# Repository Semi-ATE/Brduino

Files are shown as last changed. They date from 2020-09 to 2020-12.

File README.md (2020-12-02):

# Brduino-Nano

Brduino-Nano is a 'jeux de mots vis-à-vis' [Arduino-Nano](https://store.arduino.cc/arduino-nano).

It is an open-source project sponsored by [RevisionOne](https://www.revisionone.de/) that brings the Arduino-Nano form-factor into this century. :sunglasses:

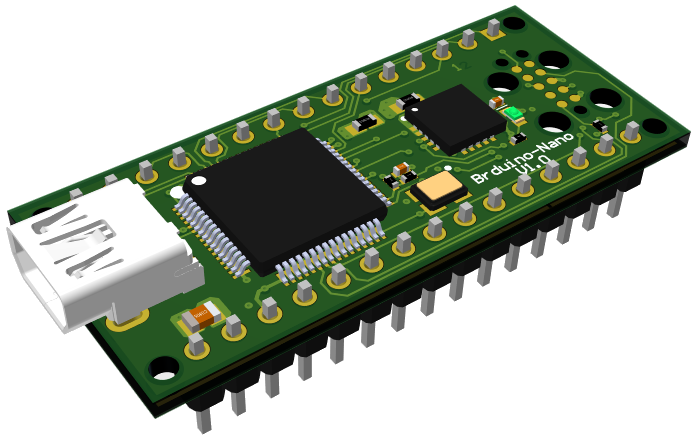
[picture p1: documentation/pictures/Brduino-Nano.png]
Brduino-Nano


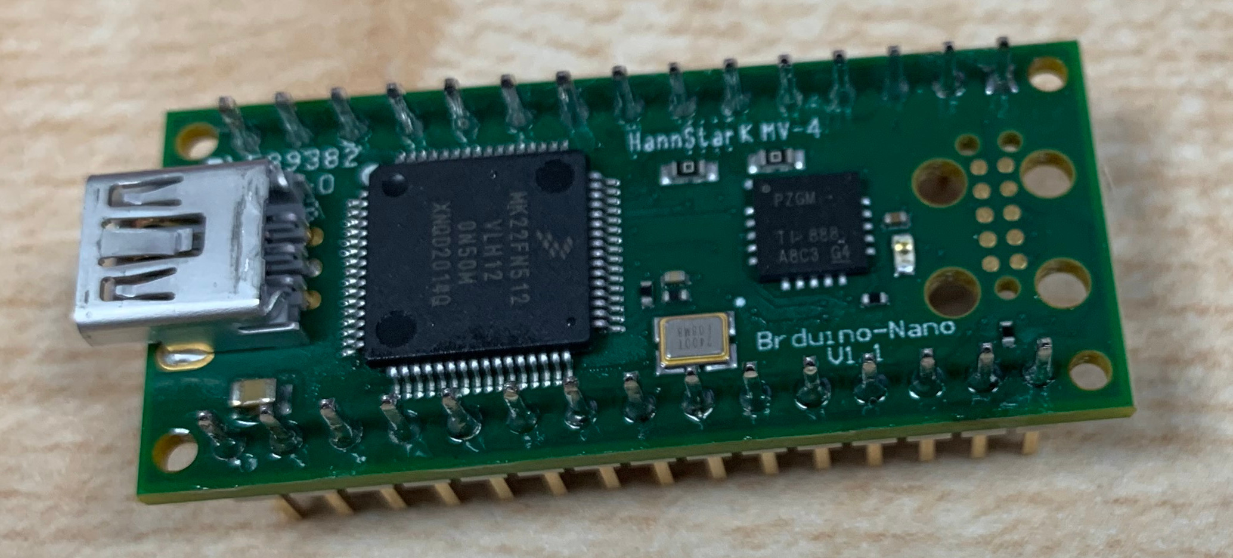
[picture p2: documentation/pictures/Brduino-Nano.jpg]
Brduino-Nano


Whereas the Arduino Nano is based on the [8-Bit ATmega328](https://www.microchip.com/wwwproducts/en/ATmega328) controller from [Microchip](https://www.microchip.com/), the Brduino Nano is based on the [32-Bit Arm Cortex M4](https://developer.arm.com/ip-products/processors/cortex-m/cortex-m4) from [NXP](https://www.nxp.com/part/MK22FN512VLH12#/). 
Below a quick comparison of the Arduino-Nano against the Brduino-Nano :

|  | Arduino-Nano | Brduino-Nano | 
|---|:---|:---|
| Microcontroller | [ATmega328](https://www.microchip.com/wwwproducts/en/ATmega328) | [MK22FN512VLH12](https://www.nxp.com/part/MK22FN512VLH12#/) |
| Architecture | 8-Bit AVR | 32-Bit Cortex M4 |
| Operating Voltage |  5 V | 3.3 V |
| Flash Memory | 32 KB | 512 KB |
| SRAM | 2 KB | 128 KB |
| Clock Speed | 16 MHz | 120 MHz |
| DAC | N/A | 1 x 12 Bit |
| Timers | 2 x 8 Bit / 1 x 16 Bit | 1 x 16 Bit|
| ADC | 1 x 10 Bit | 2 x 16 Bit |
| Analog IN Pins | 8 | 8 |
| DC Current per I/O Pins |	40 mA (I/O Pins) | ? |
| Input Voltage | 7-12 V | 5 V |
| Digital I/O Pins | 22 (6 of which are PWM) | 22 (? of which are PWM) |
| PWM Output | 	6 | ? |
| Power Consumption | 19 mA | ? |
| PCB Size | 18 x 45 mm | 18 x 45 mm |
| Weight |	7 g | 7 g |

The Brduino ofcourse doesn't use the ugly [arduino IDE](https://www.arduino.cc/en/main/software) but the [eclipse](https://www.eclipse.org/) based [MCUXpresso](https://www.nxp.com/design/software/development-software/mcuxpresso-software-and-tools-/mcuxpresso-integrated-development-environment-ide:MCUXpresso-IDE) :stuck_out_tongue_winking_eye:.

Connecting from your IDE to the Brduino is done via a [JLink Pro](https://www.segger.com/products/debug-probes/j-link/models/j-link-pro/) in combination with the [10-Pin Needle Adapter](https://www.segger.com/products/debug-probes/j-link/accessories/adapters/10-pin-needle-adapter/).

The project is realized in [Altium Designer](https://www.altium.com/altium-designer/), but, as the gerbers are included in the repo, you can produce the Brduino yourself without having Altium license(s), or alternatively you can contact [Thomas Arul](thomasarul@likom.com.my) at [Likom](http://www.likom.com.my/) to get a quote for these things. 

When creating a project based on the Brduino-Nano, you can create a a new repository base on the [Brduino-Nano-Template](https://github.com/Semi-ATE/Brduino-Nano-Template) repository, this way you get all the 'goodies' out of the box.

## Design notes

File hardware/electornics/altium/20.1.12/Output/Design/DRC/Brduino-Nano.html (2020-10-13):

Altium

# Design Rule Verification Report

Date: | | 10/13/2020
Time: | | 1:15:41 PM
Elapsed Time: | | 00:00:01
Filename: | | C:\Users\hoeren\Desktop\Repos\Semi-ATE\Brduino-Nano\hardware\electornics\altium\20.1.12\Brduino-Nano.PcbDoc

Warnings: | | 0
Rule Violations: | | 0

## Summary

Warnings | Count
Total | 0

Rule Violations | Count
Clearance Constraint (Gap=0.7mm) (InNetClass('HV-P')),(All) | 0
Clearance Constraint (Gap=0.152mm) (All),(All) | 0
Short-Circuit Constraint (Allowed=No) (All),(All) | 0
Un-Routed Net Constraint ( (All) ) | 0
Width Constraint (Min=0.089mm) (Max=0.254mm) (Preferred=0.254mm) (IsArc and InComponent('FID*')) | 0
Width Constraint (Min=0.152mm) (Max=5.08mm) (Preferred=0.152mm) (All) | 0
Width Constraint (Min=0.152mm) (Max=0.152mm) (Preferred=0.152mm) (InDifferentialPairClass('HighSpeedDiff')) | 0
Routing Layers(All) | 0
Routing Via (MinHoleWidth=0.203mm) (MaxHoleWidth=0.508mm) (PreferredHoleWidth=0.203mm) (MinWidth=0.508mm) (MaxWidth=1.016mm) (PreferedWidth=0.508mm) (All) | 0
Differential Pairs Uncoupled Length using the Gap Constraints (Min=0.152mm) (Max=0.254mm) (Prefered=0.152mm) and Width Constraints (Min=0.195mm) (Max=0.381mm) (Prefered=0.195mm) (InDifferentialPair('CPUSIGA.USB-D_1')) | 0
Differential Pairs Uncoupled Length using the Gap Constraints (Min=0.156mm) (Max=0.256mm) (Prefered=0.156mm) and Width Constraints (Min=0.152mm) (Max=0.381mm) (Prefered=0.152mm) (InDifferentialPairClass('HighSpeedDiff')) | 0
Power Plane Connect Rule(Direct Connect )(Expansion=0.508mm) (Conductor Width=0.254mm) (Air Gap=0.254mm) (Entries=4) (All) | 0
Hole Size Constraint (Min=0.2mm) (Max=5.08mm) (All) | 0
Pads and Vias to follow the Drill pairs settings | 0
Hole To Hole Clearance (Gap=0.254mm) (All),(All) | 0
Minimum Solder Mask Sliver (Gap=0.08mm) (Disabled)(All),(All) | 0
Net Antennae (Tolerance=0mm) (Disabled)(All) | 0
Matched Lengths(Tolerance=0.254mm) (InxSignalClass('RMII-IF')) | 0
Matched Lengths(Tolerance=1mm) (InDifferentialPair('ETH-TX_8') or InDifferentialPair('ETH-RX_8') or InDifferentialPair('CPUSIGA.USB-D_1')) | 0
Room U_Brduino-MCU1 (Bounding Region = (29.769mm, 76.759mm, 70.256mm, 90.424mm) (InComponentClass('U_Brduino-MCU1')) | 0
Room Brduino-Main (Bounding Region = (25.721mm, 73.721mm, 69.967mm, 93.583mm) (InComponentClass('Brduino-Main')) | 0
Room U_Brduino-MCU-Main (Bounding Region = (23.749mm, 76.81mm, 53.34mm, 89.383mm) (Disabled)(InComponentClass('U_Brduino-MCU-Main')) | 0
Room U_Brduino-PwrLin (Bounding Region = (52.095mm, 79.451mm, 64.287mm, 88.748mm) (Disabled)(InComponentClass('U_Brduino-PwrLin')) | 0
Height Constraint (Min=0mm) (Max=25.4mm) (Prefered=12.7mm) (Disabled)(All) | 0
Total | 0

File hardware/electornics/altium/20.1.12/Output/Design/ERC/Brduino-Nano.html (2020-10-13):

Altium

# Electrical Rule Check Report

Date: | | 10/13/2020
Time: | | 1:15:40 PM
Filename: | | C:\Users\hoeren\Desktop\Repos\Semi-ATE\Brduino-Nano\hardware\electornics\altium\20.1.12\.\Output\Design\ERC\Brduino-Nano.html

Class | Document | Message
Warning | Brduino-Main.SchDoc | Net 5V has no driving source (Pin C20-2, Pin C21-2, Pin J1-27, Pin J1-30, Pin J5-1, Pin R25-1, Pin U2-12, Pin U2-14, Pin U2-15, Pin U2-16, Pin U2-17)
Warning | Brduino-PwrLin.SchDoc | Net NetC19_2 has no driving source (Pin C19-2, Pin U2-3)
Warning | Brduino-PwrLin.SchDoc | Net NetC22_1 has no driving source (Pin C22-1, Pin U2-13)
Warning | Brduino-MCU1.SchDoc | Net NetU1_20 has no driving source (Pin U1-20, Pin Y1-1)
Warning | Brduino-MCU1.SchDoc | Net VBAT_M_3 has no driving source (Pin R4-1, Pin U1-21)
Warning | Brduino-MCU1.SchDoc | Net Vregin_3 has no driving source (Pin C5-1, Pin R1-2, Pin R10-2, Pin U1-8)
Warning | Brduino-Main.SchDoc | Nets Wire 3V3 has multiple names (Net Label PowerOut, Port PowerOut, Power Object 3V3, Power Object 3V3, Power Object 3V3, Power Object 3V3, Power Object 3V3, Power Object 3V3, Power Object 3V3, Power Object 3V3, Power Object 3V3, Power Object 3V3, Power Object 3V3, Power Object 3V3, Sheet Entry U_Brduino-PwrLin-PowerOut(Passive))
Warning | Brduino-Main.SchDoc | Nets Wire 5V has multiple names (Net Label Bias, Net Label PowerIn, Net Label PowerIn, Port Bias, Port PowerIn, Power Object 5V, Power Object 5V, Power Object 5V, Power Object 5V, Sheet Entry U_Brduino-PwrLin-Bias(Input), Sheet Entry U_Brduino-PwrLin-PowerIn(Input))
Warning | Brduino-MCU-Main.SchDoc | Nets Wire EXTAL0_2 has multiple names (Net Label EXTAL0, Net Label EXTAL0, Net Label PTA18, Net Label PTA18, Port PTA18, Sheet Entry U_Brduino-MCU1-PTA18(I/O))
Warning | Brduino-Main.SchDoc | Nets Wire PGOOD1_1 has multiple names (Net Label PGOOD, Net Label PGOOD, Net Label PGOOD1, Port PGOOD, Sheet Entry U_Brduino-PwrLin-PGOOD(Output))
Warning | Brduino-MCU-Main.SchDoc | Nets Wire PTA19_2 has multiple names (Net Label PTA19, Net Label PTA19, Net Label XTAL0, Net Label XTAL0, Port PTA19, Sheet Entry U_Brduino-MCU1-PTA19(I/O))
Warning | Brduino-MCU-Main.SchDoc | Nets Wire PTC6_2 has multiple names (Net Label PTC6, Net Label PTC6, Net Label USB-V-Bus, Net Label USB-V-Bus, Port PTC6, Sheet Entry U_Brduino-MCU1-PTC6(I/O))
Warning | Brduino-MCU-Main.SchDoc | Nets Wire USB-D_2_N has multiple names (Net Label USB-D_N, Net Label USB-D_N, Net Label USB_N, Net Label USB_N, Port USB_N, Sheet Entry U_Brduino-MCU1-USB_N(I/O))
Warning | Brduino-MCU-Main.SchDoc | Nets Wire USB-D_2_P has multiple names (Net Label USB-D_P, Net Label USB-D_P, Net Label USB_P, Net Label USB_P, Port USB_P, Sheet Entry U_Brduino-MCU1-USB_P(I/O))
Warning | Brduino-Main.SchDoc | Nets Wire VREF_1 has multiple names (Net Label VREF, Net Label VREF, Net Label VREF_OUT, Net Label VREF_OUT, Net Label VREF_OUT, Port VREF_OUT, Port VREF_OUT, Sheet Entry U_Brduino-MCU1-VREF_OUT(I/O), Sheet Entry U_Brduino-MCU-Main-VREF_OUT(I/O))

Back to top

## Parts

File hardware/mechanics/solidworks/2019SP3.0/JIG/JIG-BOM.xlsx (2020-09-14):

Part | Description | Manufacturer | MPN | Supplier | SPN | Qty | Supplier Price | Total Price
Cover_top | Cover top plate |  |  | Likom |  | 1 |  | 0
Cover_short | Cover left/right plates |  |  | Likom |  | 2 |  | 0
Cover_long | Cover front/rear plates |  |  | Likom |  | 2 |  | 0
Needlebed | Needlebed plate |  |  | Likom |  | 1 |  | 0
ISO 7046 M3x10 | Countersunk flat head cross recess screw |  |  | Likom |  | 6 |  | 0
ISO 4762 M4x16 | Socket head cap screw |  |  | Likon |  | 22 |  | 0
ISO 4762 M3x16 | Socket head cap screw |  |  | Likom |  | 2 |  | 0
JBH6-10 | bushing for locating pin | MiSUMi | JBH6-10 | MiSUMi | JBH6-10 | 2 | 7.4 | 14.8
SFTF6-55-J5-M3 | Locating pin | MiSUMi | SFTF6-55-J5-M3 | MiSUMi | SFTF6-55-J5-M3 | 2 | 13.2 | 26.4
 |  |  |  |  |  |  |  | 41.2

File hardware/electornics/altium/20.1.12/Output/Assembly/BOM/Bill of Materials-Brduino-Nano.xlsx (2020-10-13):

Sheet: BOM Report
Bill of Material for : | Brduino-Nano
Repository : | https://github.com/Semi-ATE/Brduino-Nano |  | Organization : | RevisionOne
Project Nr. : | U33115 |  | Engineer : | Mörz
Revision : | V1.1 |  | Draftsman : | Mörz
Variant : | None |  | Reviewer : | Hören
 |  |  |  | Manufacturer |  |  | Supplier
Description | Designator(s) | Value | Foot Print | Name | Part Number | Qty | Name | Part Number | UP [€] | TP [€]
CAP CER 0.1UF 25V X7R 0402 | C1, C2, C4, C5, C6, C9, C10, C11, C12, C13 | 100nF | C0402 | Yageo | CC0402KRX7R8BB104 | 10 | DigiKey | 311-2077-6-ND | 0.08 | 0.80 €
CAP CER 2.2UF 10V X5R 0603 | C3 | 2u2F | C0603 | Samsung Electro-Mechanics | CL10A225KP8NNNC | 1 | DigiKey | 1276-1085-6-ND | 0.08 | 0.08 €
CAP CER 10UF 10V X7R 0805 | C7, C8 | 10uF | C0805 | Murata Electronics | GRM21BR71A106KA73L | 2 | DigiKey | 490-10516-6-ND | 0.21 | 0.42 €
CAP CER 4.7UF 10V X7R 0805 | C14 | 4u7F | C0805 | Samsung Electro-Mechanics | CL21B475KPFNNNE | 1 | DigiKey | 1276-2972-6-ND | 0.21 | 0.21 €
CAP CER 22PF 16V C0G/NP0 0402 | C16, C17 | 22pF | C0402 | KEMET | C0402C220J4GACTU | 2 | DigiKey | 399-8954-6-ND | 0.08 | 0.16 €
CAP CER 22UF 10V X5R 0805 | C18 | 22uF | C0805 | Murata Electronics | GRM21BR61A226ME44# | 1 | DigiKey | 490-10746-6-ND | 0.49 | 0.49 €
CAP CER 10000PF 50V X7R 0402 | C19, C22 | 10nF | C0402 | Murata Electronics | GRM155R71H103KA88D | 2 | DigiKey | 490-4516-6-ND | 0.08 | 0.16 €
CAP CER 10UF 25V X5R 0805 | C20, C21 | 10uF | C0805 | Murata Electronics | GRM21BR61E106KA73L | 2 | DigiKey | 490-5523-6-ND | 0.37 | 0.74 €
DIODE ARRAY SCHOTTKY 30V SOT23-3 | D1 |  | SOT23 | ONSEMI | BAT54C | 1 | DigiKey | BAT54CFSCT-ND | 0.18 | 0.18 €
LED GREEN CLEAR 1608 SMD | D6 | Green | LED0603 | KINGBRIGHT | APHD1608LCGCK | 1 | DigiKey | 754-2031-6-ND | 0.34 | 0.34 €
CONN RCPT USB2.0 MINI AB 5P R/A | J3 |  | Molex-0565790519 | Molex | 0565790519 | 1 | DigiKey | WM17121-ND | 2.04 | 2.04 €
RES SMD 0 OHM JUMPER 1/10W 0603 | J4, J5 | 0R | JumperSMD | Yageo | RC0603JR-070RL | 2 | DigiKey | 311-0.0GRDKR-ND | 0.08 | 0.16 €
FERRITE BEAD 600 OHM 0805 1LN | L1 | 600R@100MHz | L0805 | WUERTH | 742792040 | 1 | DigiKey | 732-1620-6-ND | 0.18 | 0.18 €
MOSFET N-CHANNEL 30V 1A SC70 | Q1 |  | SOT323 | NEXPERIA | PMF250XNEX | 1 | DigiKey | 1727-2693-6-ND | 0.31 | 0.31 €
RES SMD 0 OHM JUMPER 1/16W 0402 | R1, R5, R10 | 0R | R0402 | Yageo | RC0402JR-070RL | 3 | DigiKey | 311-0.0JRDKR-ND | 0.08 | 0.24 €
RES SMD 4.7K OHM 1% 1/16W 0402 | R2, R15, R20 | 4K7 | R0402 | Yageo | RC0402FR-074K7L | 3 | DigiKey | 311-4.7KLRDKR-ND | 0.08 | 0.24 €
RES SMD 22 OHM 1% 1/16W 0402 | R3 | 22R | R0402 | Yageo | RC0402FR-0722RL | 1 | DigiKey | 311-22.0LRDKR-ND | 0.08 | 0.08 €
RES SMD 100 OHM 1% 1/16W 0402 | R4 | 100R | R0402 | Yageo | RC0402FR-07100RL | 1 | DigiKey | 311-100LRDKR-ND | 0.08 | 0.08 €
RES SMD 10K OHM 1% 1/16W 0402 | R6, R8, R16 | 10K | R0402 | Yageo | RC0402FR-0710KL | 3 | DigiKey | 311-10.0KLRDKR-ND | 0.08 | 0.24 €
RES SMD 33 OHM 1% 1/16W 0402 | R7 | 33R | R0402 | Yageo | RC0402FR-0733RL | 1 | DigiKey | 311-33.0LRDKR-ND | 0.08 | 0.08 €
RES SMD 1M OHM 1% 1/16W 0402 | R9 | 1M | R0402 | Yageo | RC0402FR-071ML | 1 | DigiKey | 311-1.00MLRDKR-ND | 0.08 | 0.08 €
RES SMD 3.9K OHM 1% 1/16W 0402 | R25 | 3K9 | R0402 | Yageo | RC0402FR-073K9L | 1 | DigiKey | 311-3.90KLRDKR-ND | 0.08 | 0.08 €
IC MCU 32BIT 512KB FLASH 64LQFP | U1 |  | NXP-SOT1699-1 | NXP USA Inc. | MK22FN512VLH12 | 1 | DigiKey | MK22FN512VLH12-ND | 7.16 | 7.16 €
IC REG LINEAR POS ADJ 2A 20VQFN | U2 |  | S-PVQFN-N20 | Texas Instruments | TPS7A8300RGWT | 1 | DigiKey | 296-36510-6-ND | 4.57 | 4.57 €
CONN HEADER VERT 15POS 2.54MM | X1, X2 |  |  | Samtec Inc. | HTSW-115-08-F-S | 2 | DigiKey | HTSW-115-08-F-S-ND | 1.03 | 2.06 €
Crystals 32.768 kHz 9.0 pF +/-20 PPM | Y1 | 32.768KHz | CM7V-T1A | Micro Crystal | CM7V-T1A-32.768k-9pF-20PPM-TA-QA T3 | 1 | Mouser | 428-201568-MG03 | 0.37 | 0.37 €
CRYSTAL 24.0000MHZ 18PF SMD | Y2 | 24.0000MHz | FA-238 | EPSON | FA-238 24.0000MB-C3 | 1 | DigiKey | SER3689DKR-ND | 0.3 | 0.30 €
 |  |  |  |  |  | 48 |  |  |  | 21.85 €

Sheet: Project Information
Project Full Path | C:\Users\hoeren\Desktop\Repos\Semi-ATE\Brduino-Nano\hardware\electornics\altium\20.1.12\Brduino-Nano.PrjPcb
Project Filename | Brduino-Nano.PrjPcb
Variant Name | None
Data-Source Filename | Brduino-Nano.PrjPcb
Data-Source Full Path | C:\Users\hoeren\Desktop\Repos\Semi-ATE\Brduino-Nano\hardware\electornics\altium\20.1.12\Brduino-Nano.PrjPcb
Title | Bill of Materials for Project [Brduino-Nano.PrjPcb] (No PCB Document Selected)
Total Quantity | 48
Report Time | 1:16 PM
Report Date | 10/13/2020
Report Date & Tine | 10/13/2020 1:16 PM
Output Name | Bill of Materials
Output Type | BOM_PartType
Output Generator Name | BOM
Output Generator Description | Bill of Materials

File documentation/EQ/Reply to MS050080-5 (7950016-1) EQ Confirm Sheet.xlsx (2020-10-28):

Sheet: EQ
瀚宇博德股份有限公司
Hannstar Board Corporation
工程問題確認單
Engineering Questions Confirm
客戶料號(Customer P/N)： |  | MS050080-5 | 日期(Date)： |  | 2020-10-12
廠內料號(HSB P/N)： |  | 7950016-1 | 製作者(Prepared by)： |  | Vincent Liu
項次 Item | 問題內容與建議 Description and Recommendation |  | 附件 Attachment | 客戶回覆 Customer Response |  | 客戶簽名 Signature & Date
Q1 | Please confirm the panelization. |  | #1 | Likom OK |  | TDK OK
Q2 | Please confirm our recommended stackup. |  | #2 |  |  | TDK OK
Q3 | We suggest adding Dummy PAD at break-away in outer layer for plating better, please confirm. |  | #3 | Likom - OK |  | TDK OK
Q4 | Board thickness control in 1.45mm+/-10% not 1.6mm, please confirm. |  |  |  |  | TDK OK
Q5 | We will add UL MARK, DC in silkscreen layer in top side, please confirm. |  |  | Likom - OK |  | TDK OK
Q6 | Soldermask color is green, Silkscreen color is white, please confirm. |  |  |  |  | TDK OK
Q7 | Surface finish is ENIG and gold thickness is 2μ", please confirm. |  |  |  |  | TDK OK
Q8 | We will not ask again for above Eqs for future revision. Please approve. |  |  |  |  | TDK OK
Q9
Q10
1.請勿修改問題與建議欄位。
Please don't modify Description and Recommendation column.
2.請於客戶回覆欄位填入回覆意見，如有附件請新增頁面。
Please enter your comment into Customer Response column, and add new sheet if any attachment.
3.回覆後請於客戶簽名欄位填入確認者及日期。
Please sign your name and date after replied.
保存期限:壹年以上 |  |  |  |  |  | S103-3-001-01A

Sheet: #1
Panel Size:3.8"*4.07" PCS Size:1.72"*0.76" (Ignore "A" & "B", they aren't match actual size)
Break-away width:8mm and no CNC Routing
1.V-CUT number total is 7.
2.We will add "MS050080-5" and "Brduino-Nano" in break-away.
3.Adding tooling and fiducial mark as below:
 | Top Side: | Round fiducial mark with Dummy dots in square shape
 | Bottom Side: | Square fiducial mark with Dummy dots in round shape

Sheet: #2
Total thickness: 58.77mil
Outer layer is 0.5oz+plating, finish copper is more than 1oz.

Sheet: #3
TOP
BOT

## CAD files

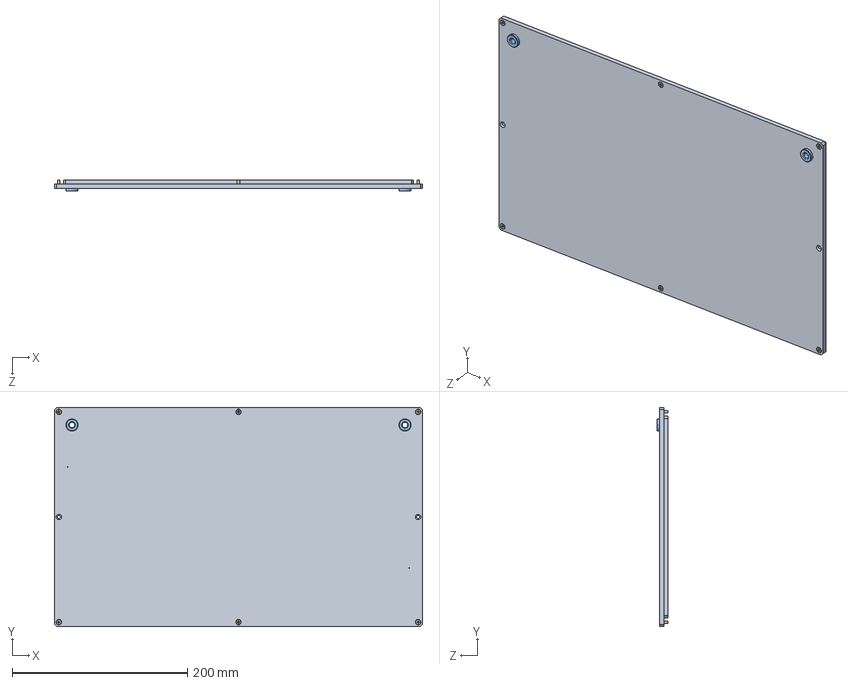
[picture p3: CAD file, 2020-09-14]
hardware/mechanics/solidworks/2019SP3.0/JIG/Needlebed.SLDASM
420.0 x 250.0 x 13.0 mm
Needlebed
countersunk flat head cross recess screw_iso x 6
JBH6_10 x 2

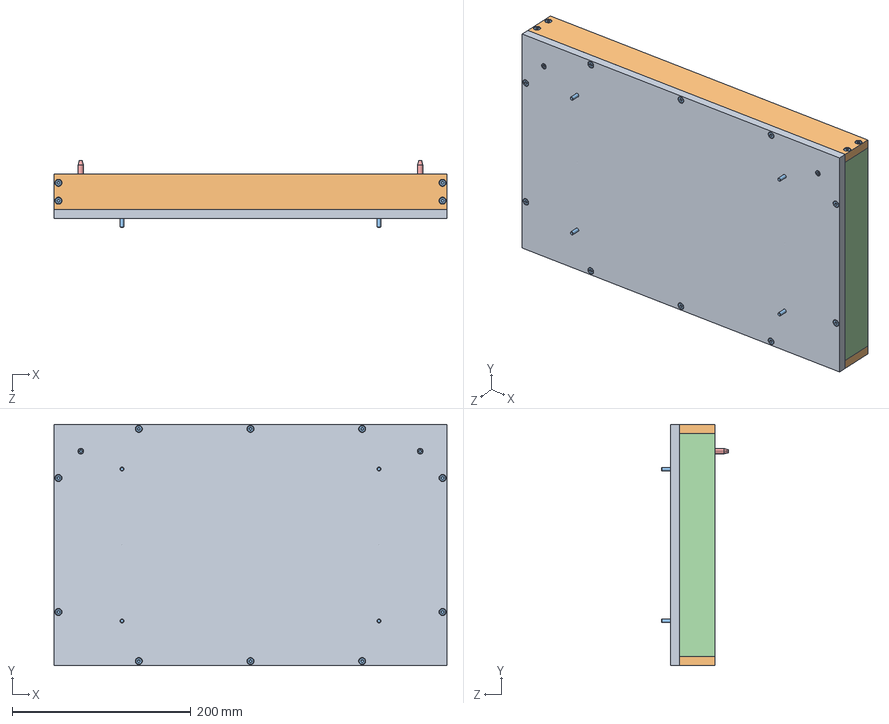
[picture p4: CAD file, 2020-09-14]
hardware/mechanics/solidworks/2019SP3.0/JIG/Cover.SLDASM
440.0 x 270.0 x 75.0 mm
Cover_top
Cover_long x 2
socket head cap screw_iso x 24
Cover_short x 2
SFTF6_55_J5_M3 x 2

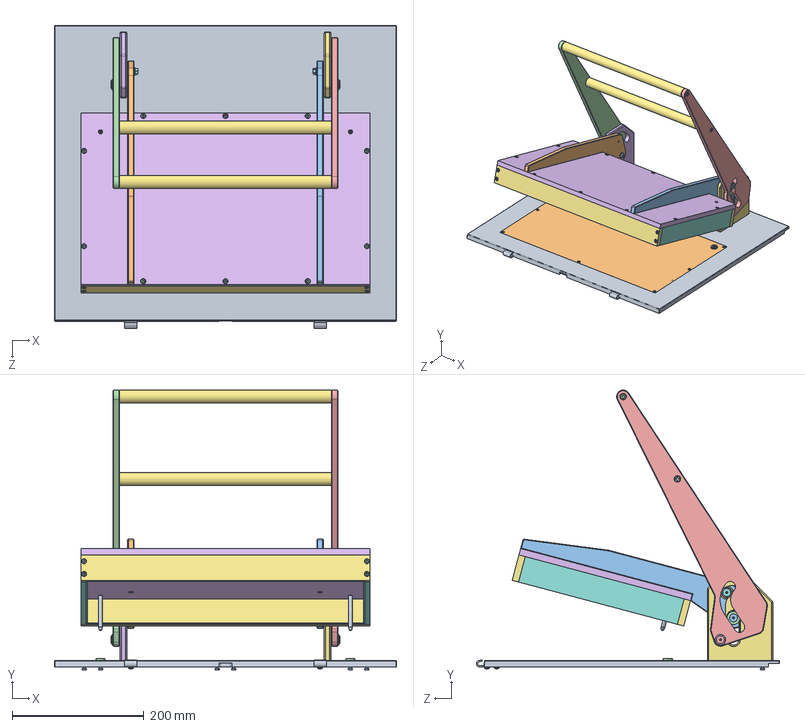
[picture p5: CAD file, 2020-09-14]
hardware/mechanics/solidworks/2019SP3.0/JIG/Fitting.SLDASM
520.0 x 425.7 x 461.0 mm
Housing_top
Lever_bottom_left
Lever_bottom_right
Lever_top_left
Lever_top_right
Spindlehouse_left
Spindlehouse_right
DBGB5-20-10 x 2
B688ZZ x 10
SWSJJ20-8-1 x 6
DBGB5-15-10 x 2
FWHJ-D16.0-H20.0-V8.0-T1.5-L4.0 x 2
DBGB5-17-5 x 2
FWHJ-D10.5-H16.0-V8.0-T1.5-L10.0 x 2
Handle x 2
FRNUT5 x 2
420111_hook x 2
pan head cross recess screw_iso x 4
slotted cheese head screw_iso x 6
socket head cap screw_iso x 32
parallel pin hardened_iso x 4
Cover_top
Cover_long x 2
Cover_short x 2
SFTF6_55_J5_M3 x 2
Needlebed
countersunk flat head cross recess screw_iso x 6
JBH6_10 x 2

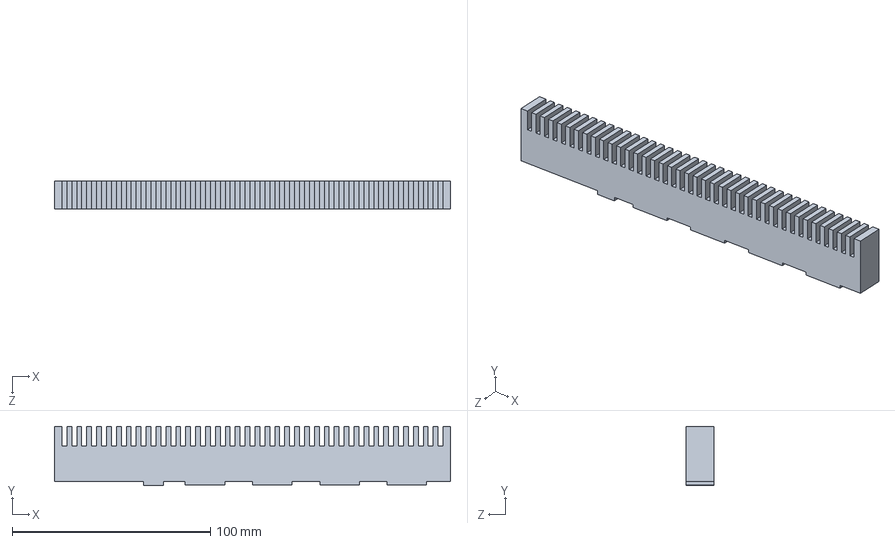
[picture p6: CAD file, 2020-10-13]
hardware/mechanics/solidworks/2019SP3.0/JIG/HeatSink.SLDPRT
200.0 x 30.0 x 14.0 mm

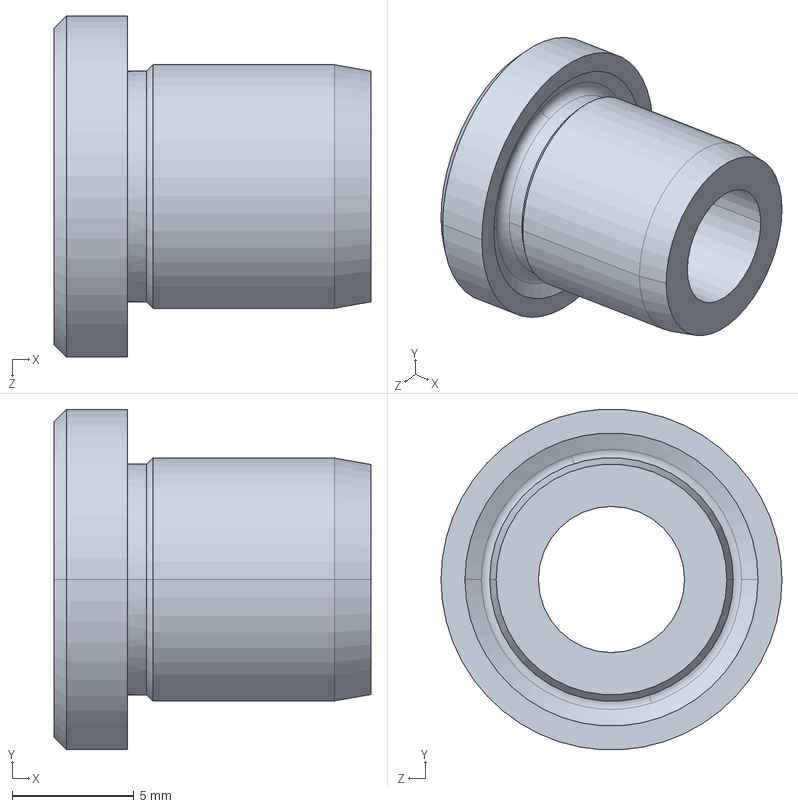
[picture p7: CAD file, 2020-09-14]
hardware/mechanics/solidworks/2019SP3.0/JIG/JBH6_10.sldprt
13.0 x 14.0 x 14.0 mm

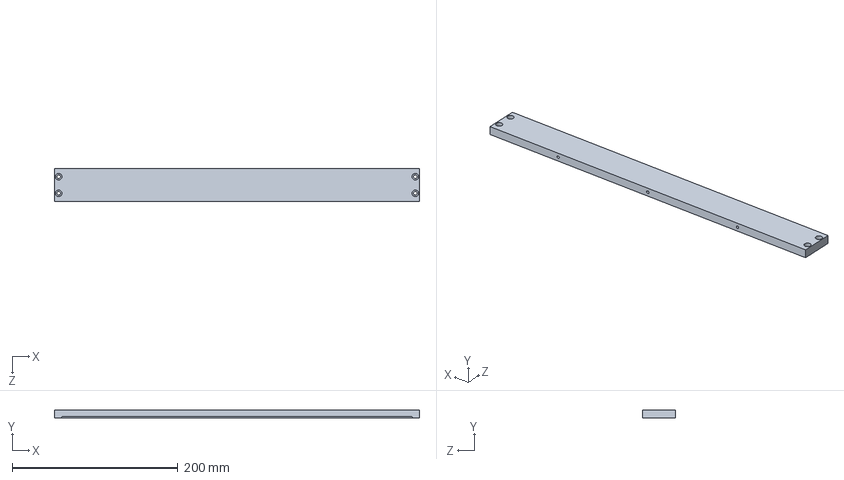
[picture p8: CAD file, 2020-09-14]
hardware/mechanics/solidworks/2019SP3.0/JIG/Cover_long.SLDPRT
440.0 x 10.0 x 40.0 mm

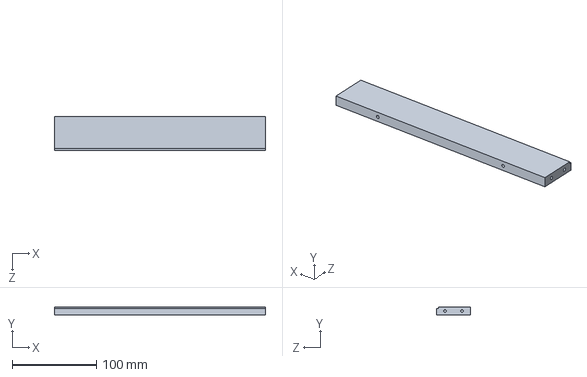
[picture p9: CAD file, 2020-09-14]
hardware/mechanics/solidworks/2019SP3.0/JIG/Cover_short.SLDPRT
250.0 x 10.0 x 40.0 mm

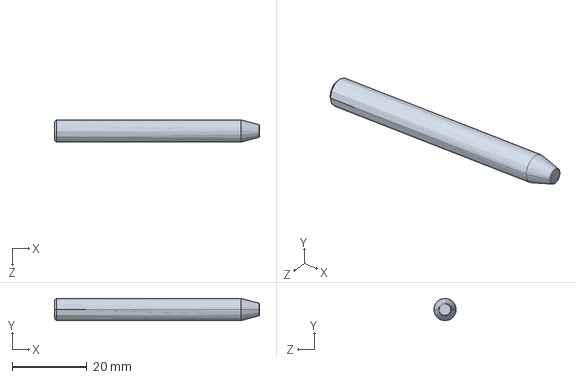
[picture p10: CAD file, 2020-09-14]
hardware/mechanics/solidworks/2019SP3.0/JIG/SFTF6_55_J5_M3.sldprt
55.0 x 6.00 x 6.00 mm

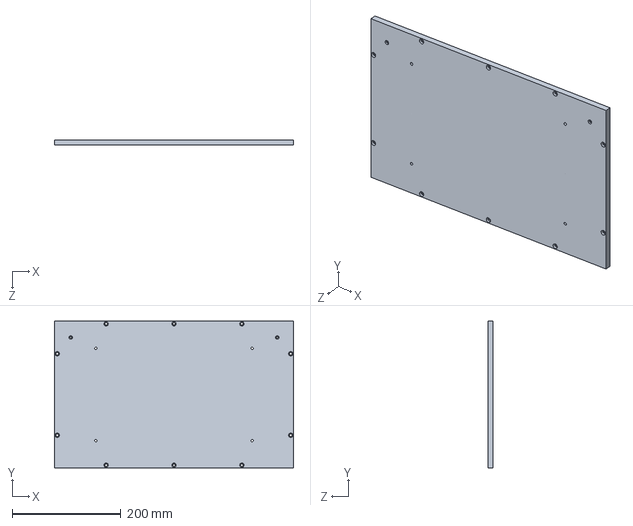
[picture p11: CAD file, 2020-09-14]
hardware/mechanics/solidworks/2019SP3.0/JIG/Cover_top.SLDPRT
440.0 x 270.0 x 10.0 mm

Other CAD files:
hardware/mechanics/solidworks/2019SP3.0/JIG/JIG.SLDDRW
hardware/mechanics/solidworks/2019SP3.0/JIG/Needlebed.SLDPRT

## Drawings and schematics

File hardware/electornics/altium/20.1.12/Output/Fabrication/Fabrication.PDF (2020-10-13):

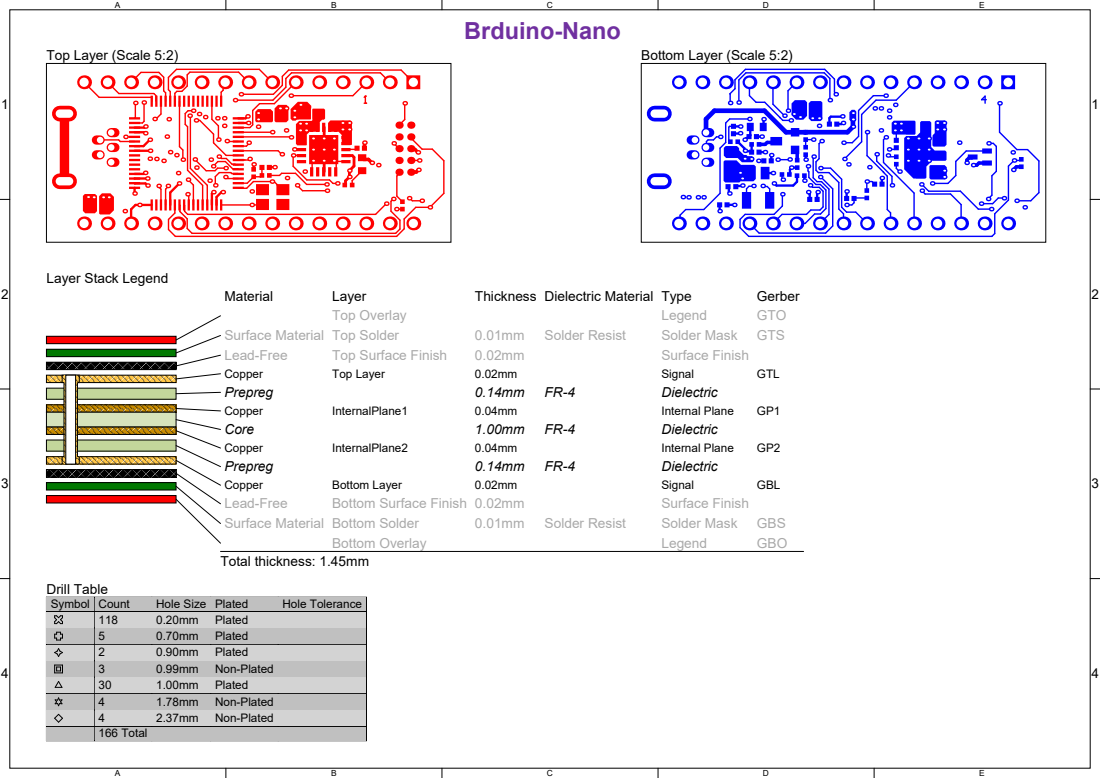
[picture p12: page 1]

Symbol | Count | Hole Size | Plated | Hole Tolerance

118 | 0.20mm | Plated
5 | 0.70mm | Plated
2 | 0.90mm | Plated
3 | 0.99mm | Non-Plated
30 | 1.00mm | Plated
4 | 1.78mm | Non-Plated
4 | 2.37mm | Non-Plated
166 Total

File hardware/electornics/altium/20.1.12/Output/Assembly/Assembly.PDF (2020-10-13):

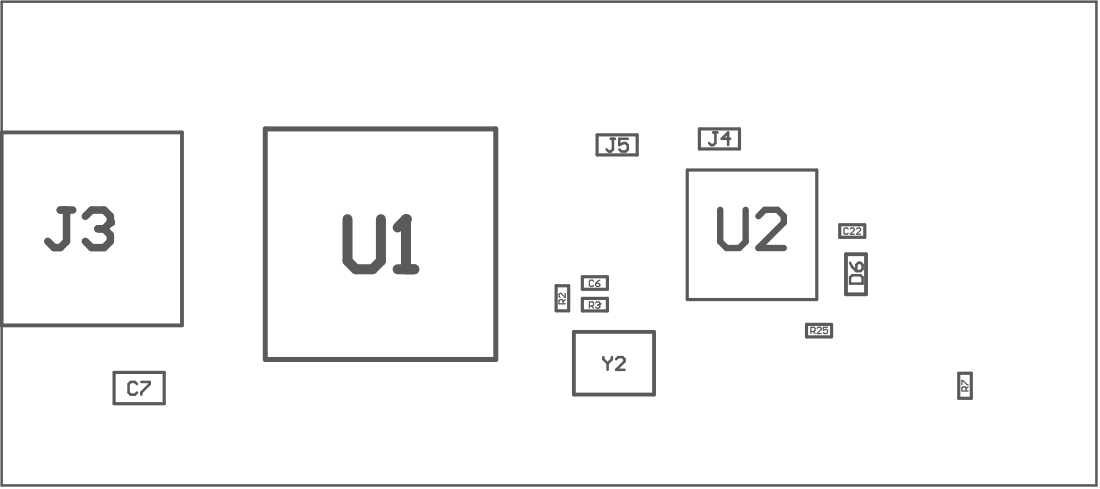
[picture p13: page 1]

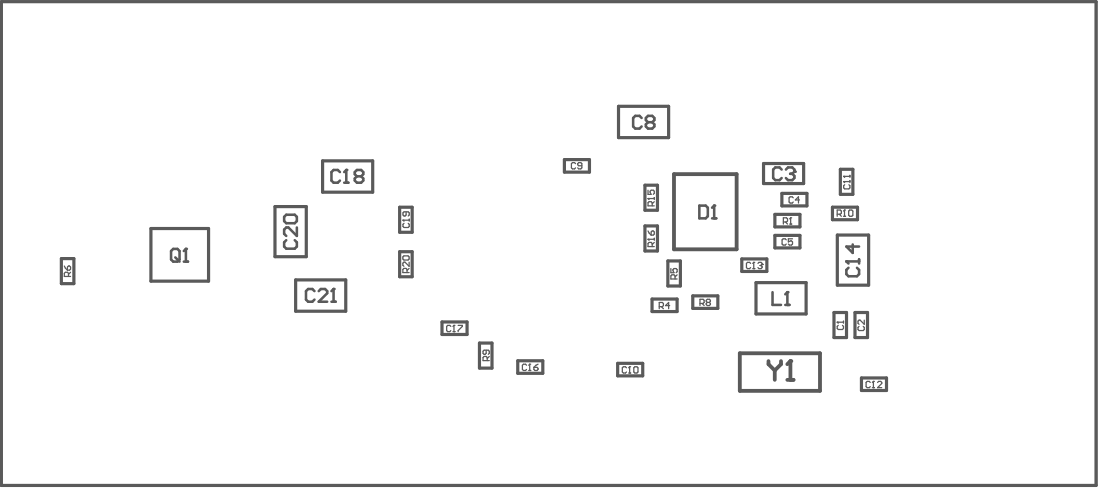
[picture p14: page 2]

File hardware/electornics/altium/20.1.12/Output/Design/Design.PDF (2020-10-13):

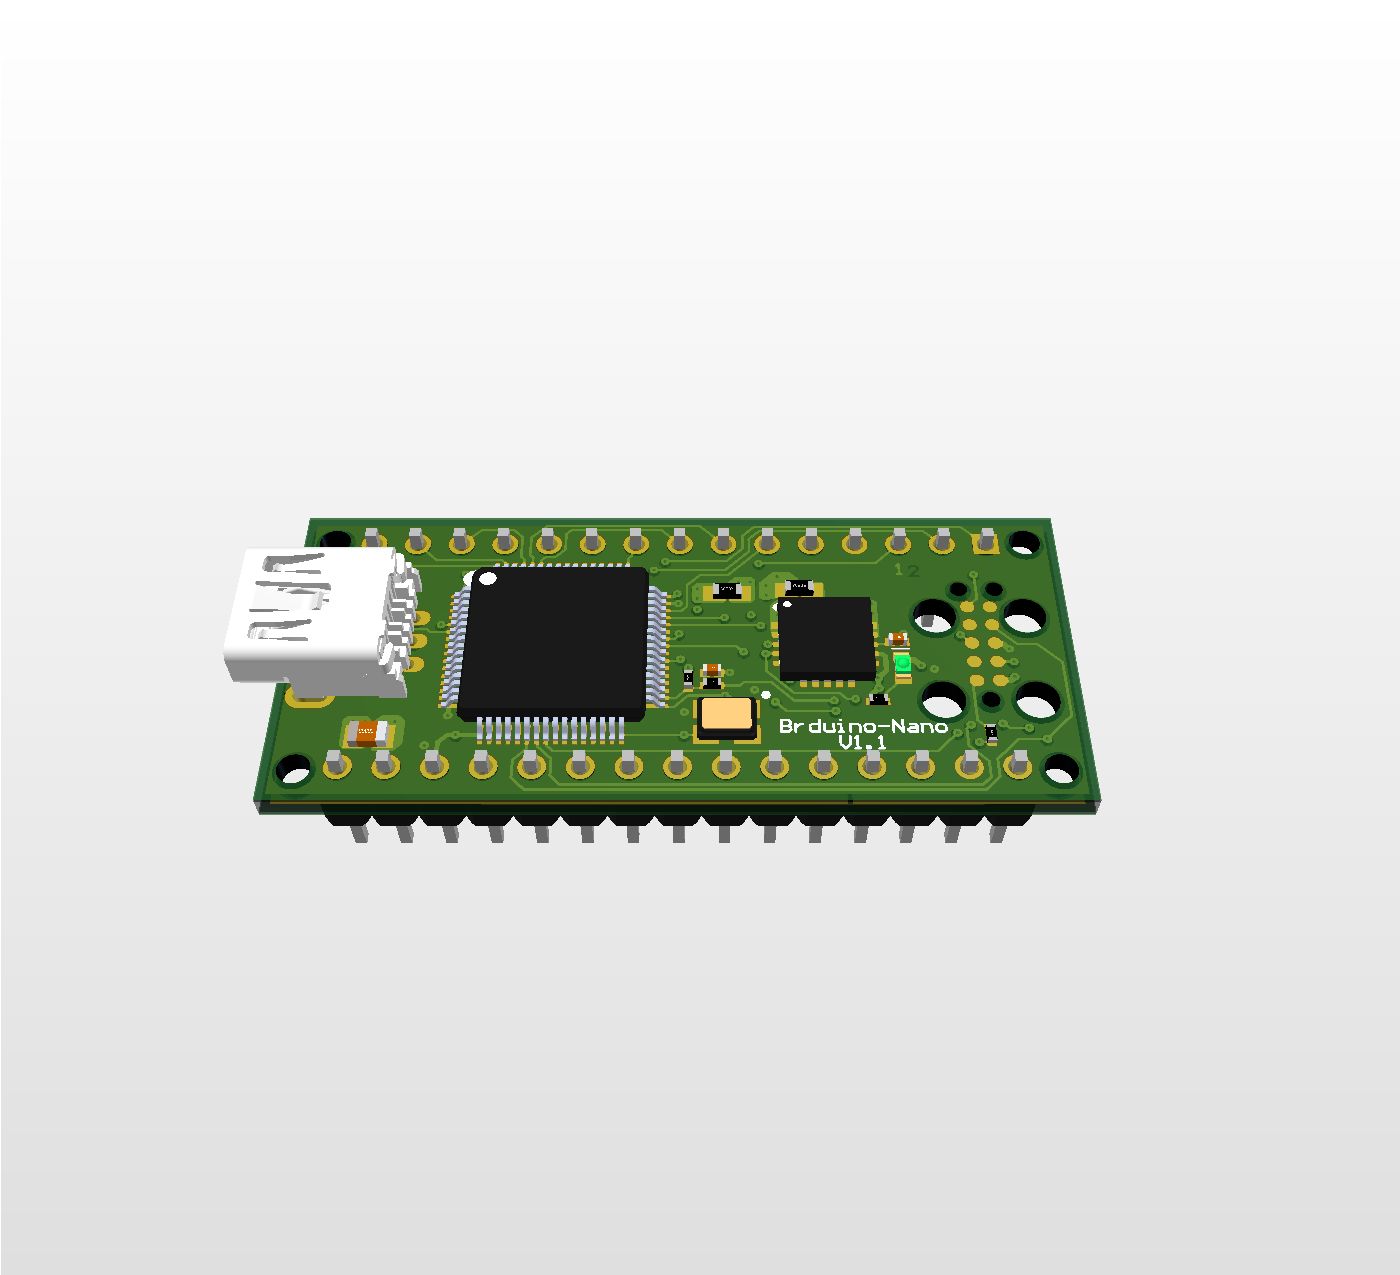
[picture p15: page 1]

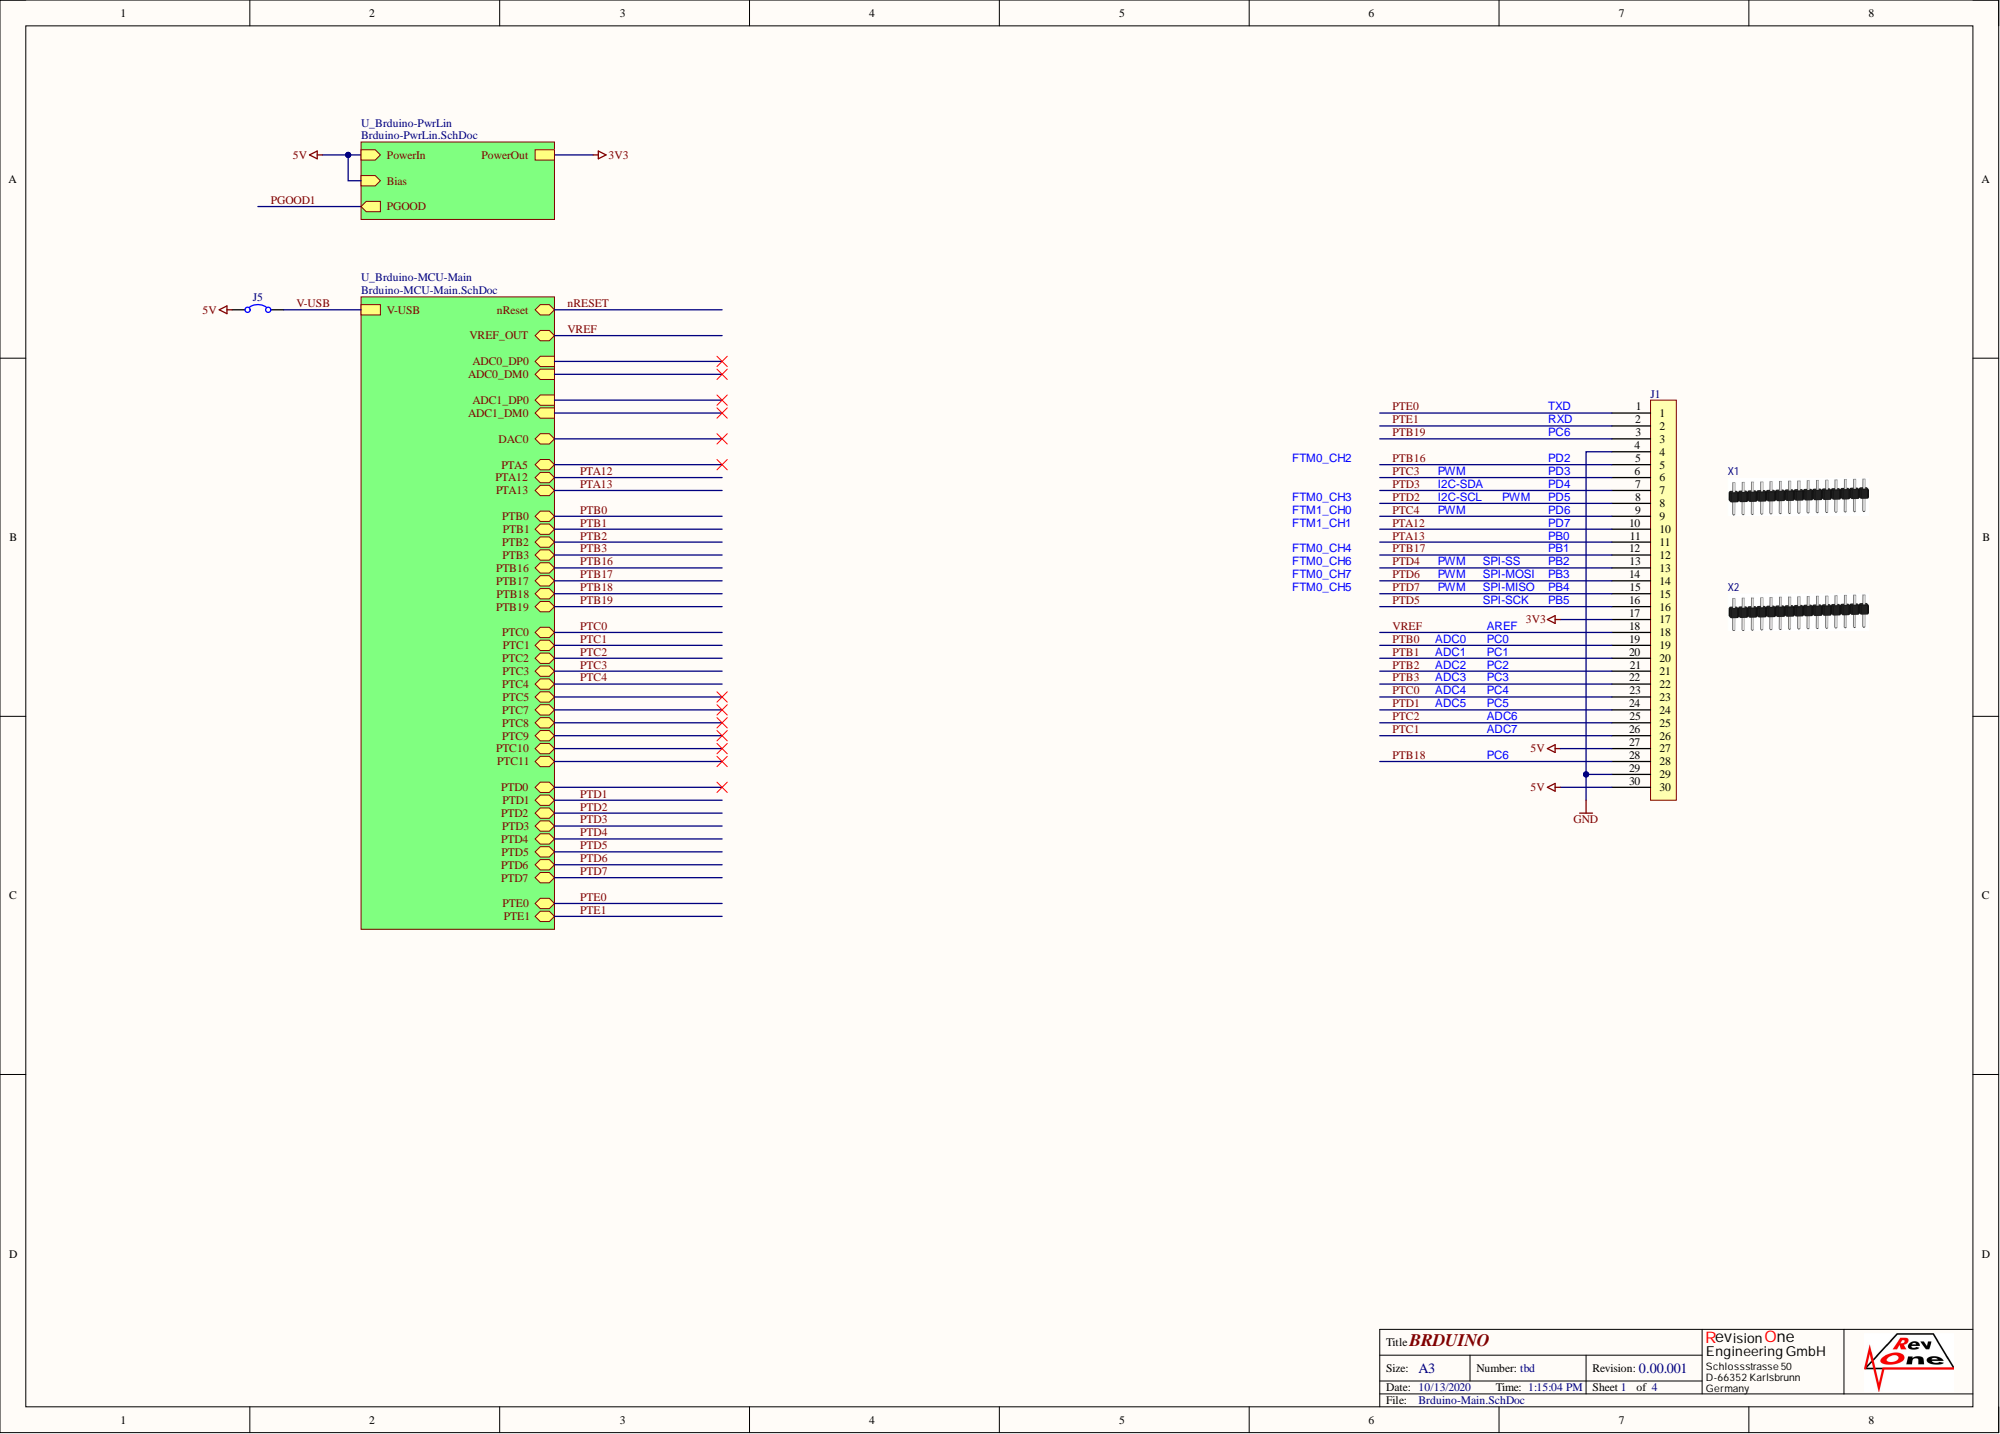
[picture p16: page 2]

U_Brduino-MCU-Main
Brduino-MCU-Main.SchDoc
V-USB

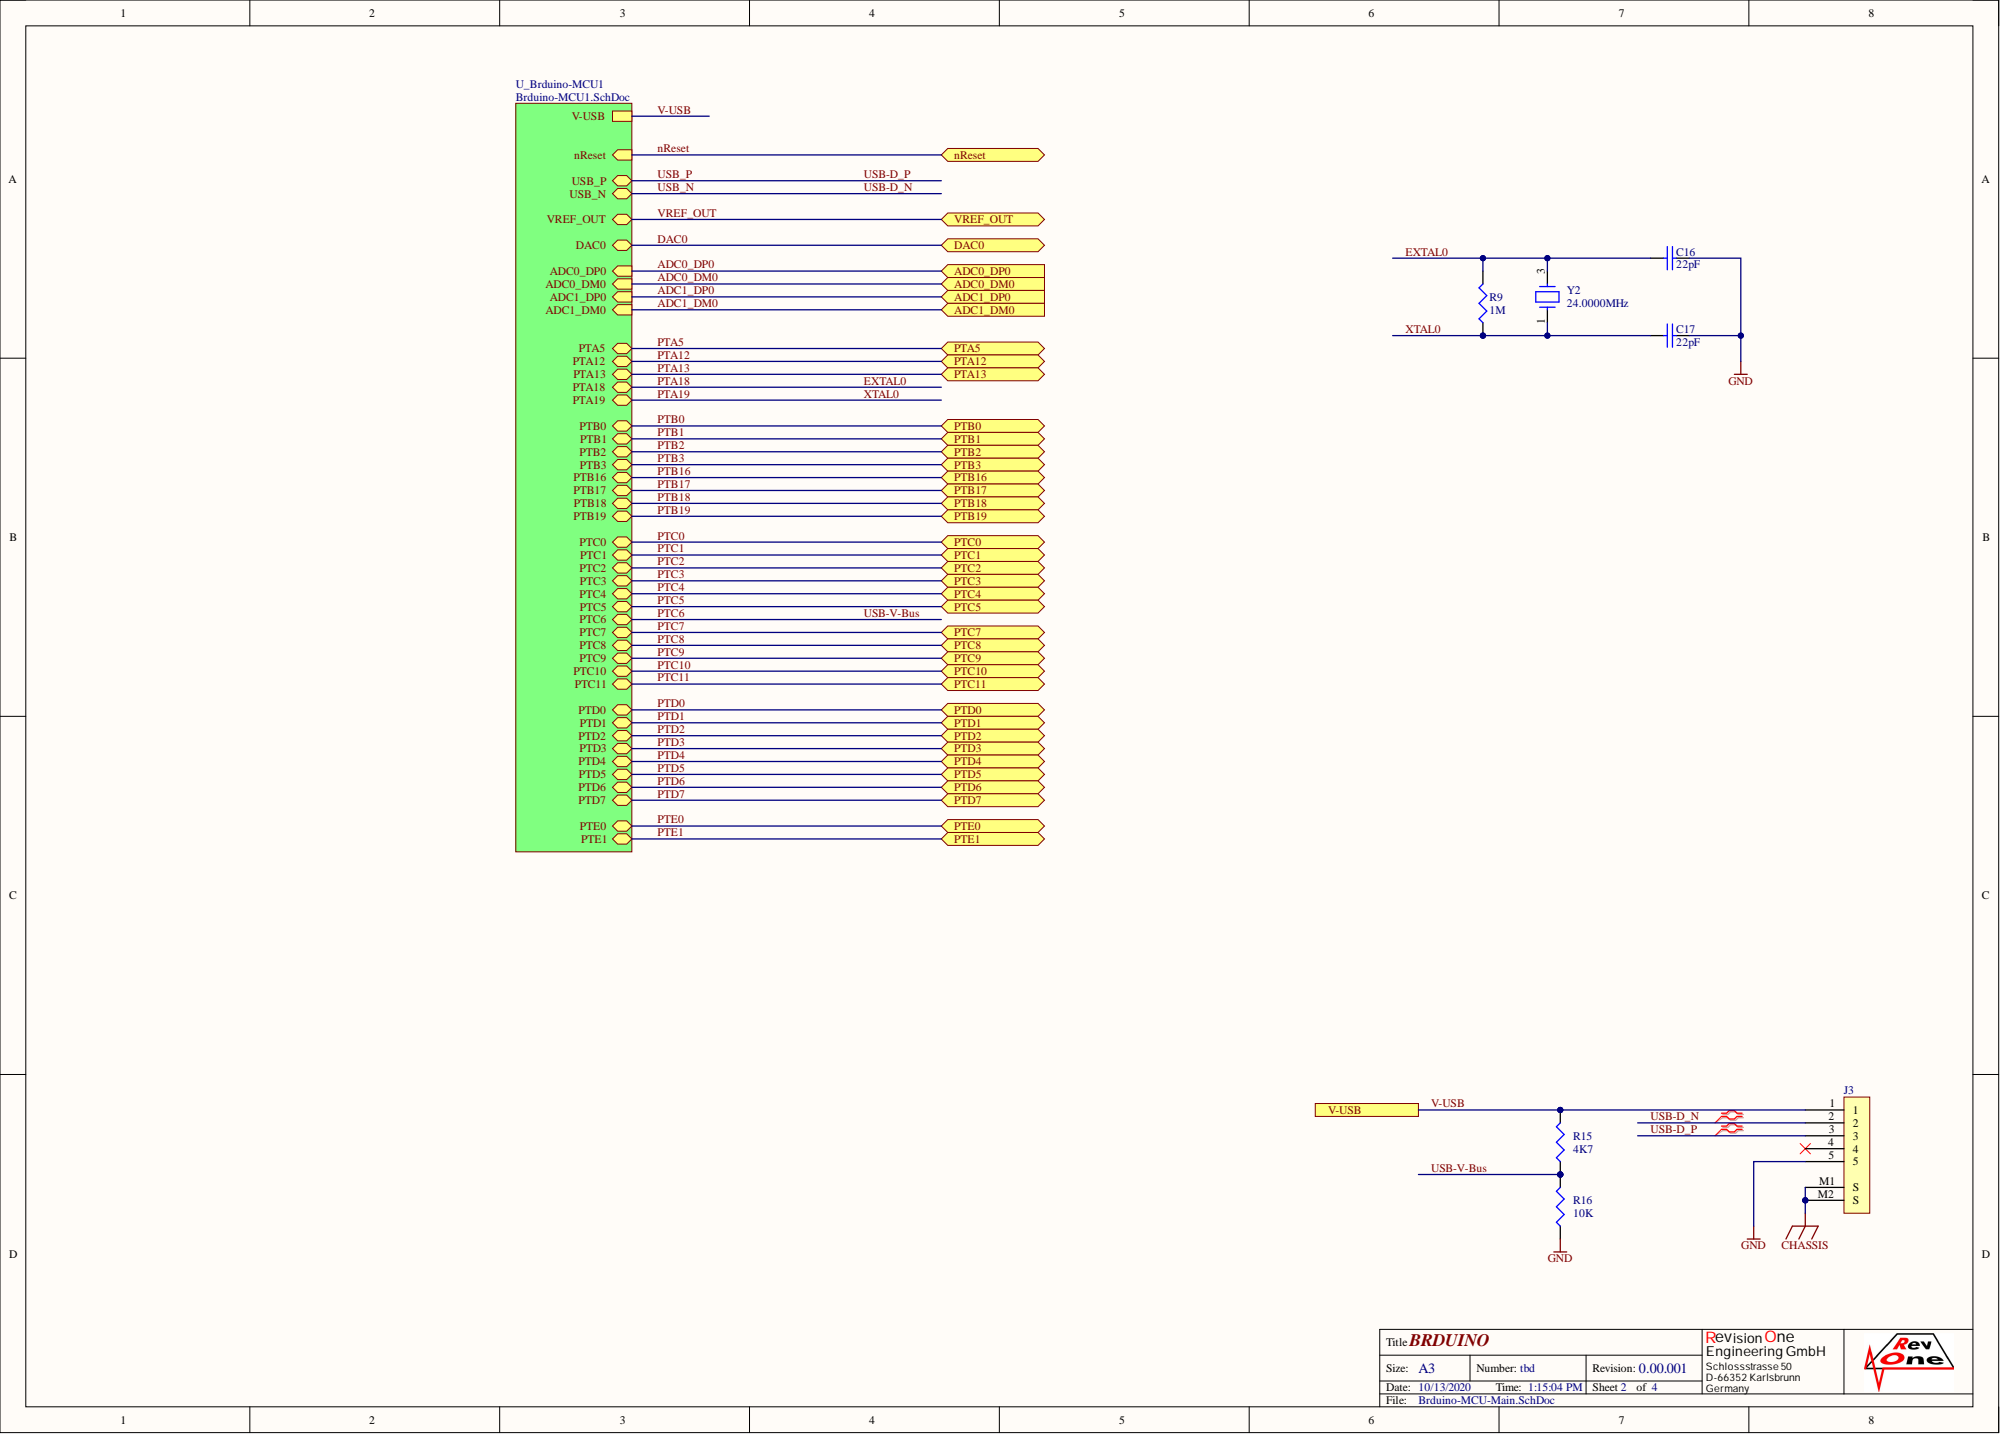
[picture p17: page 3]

Brduino-MCU-Main.SchDoc

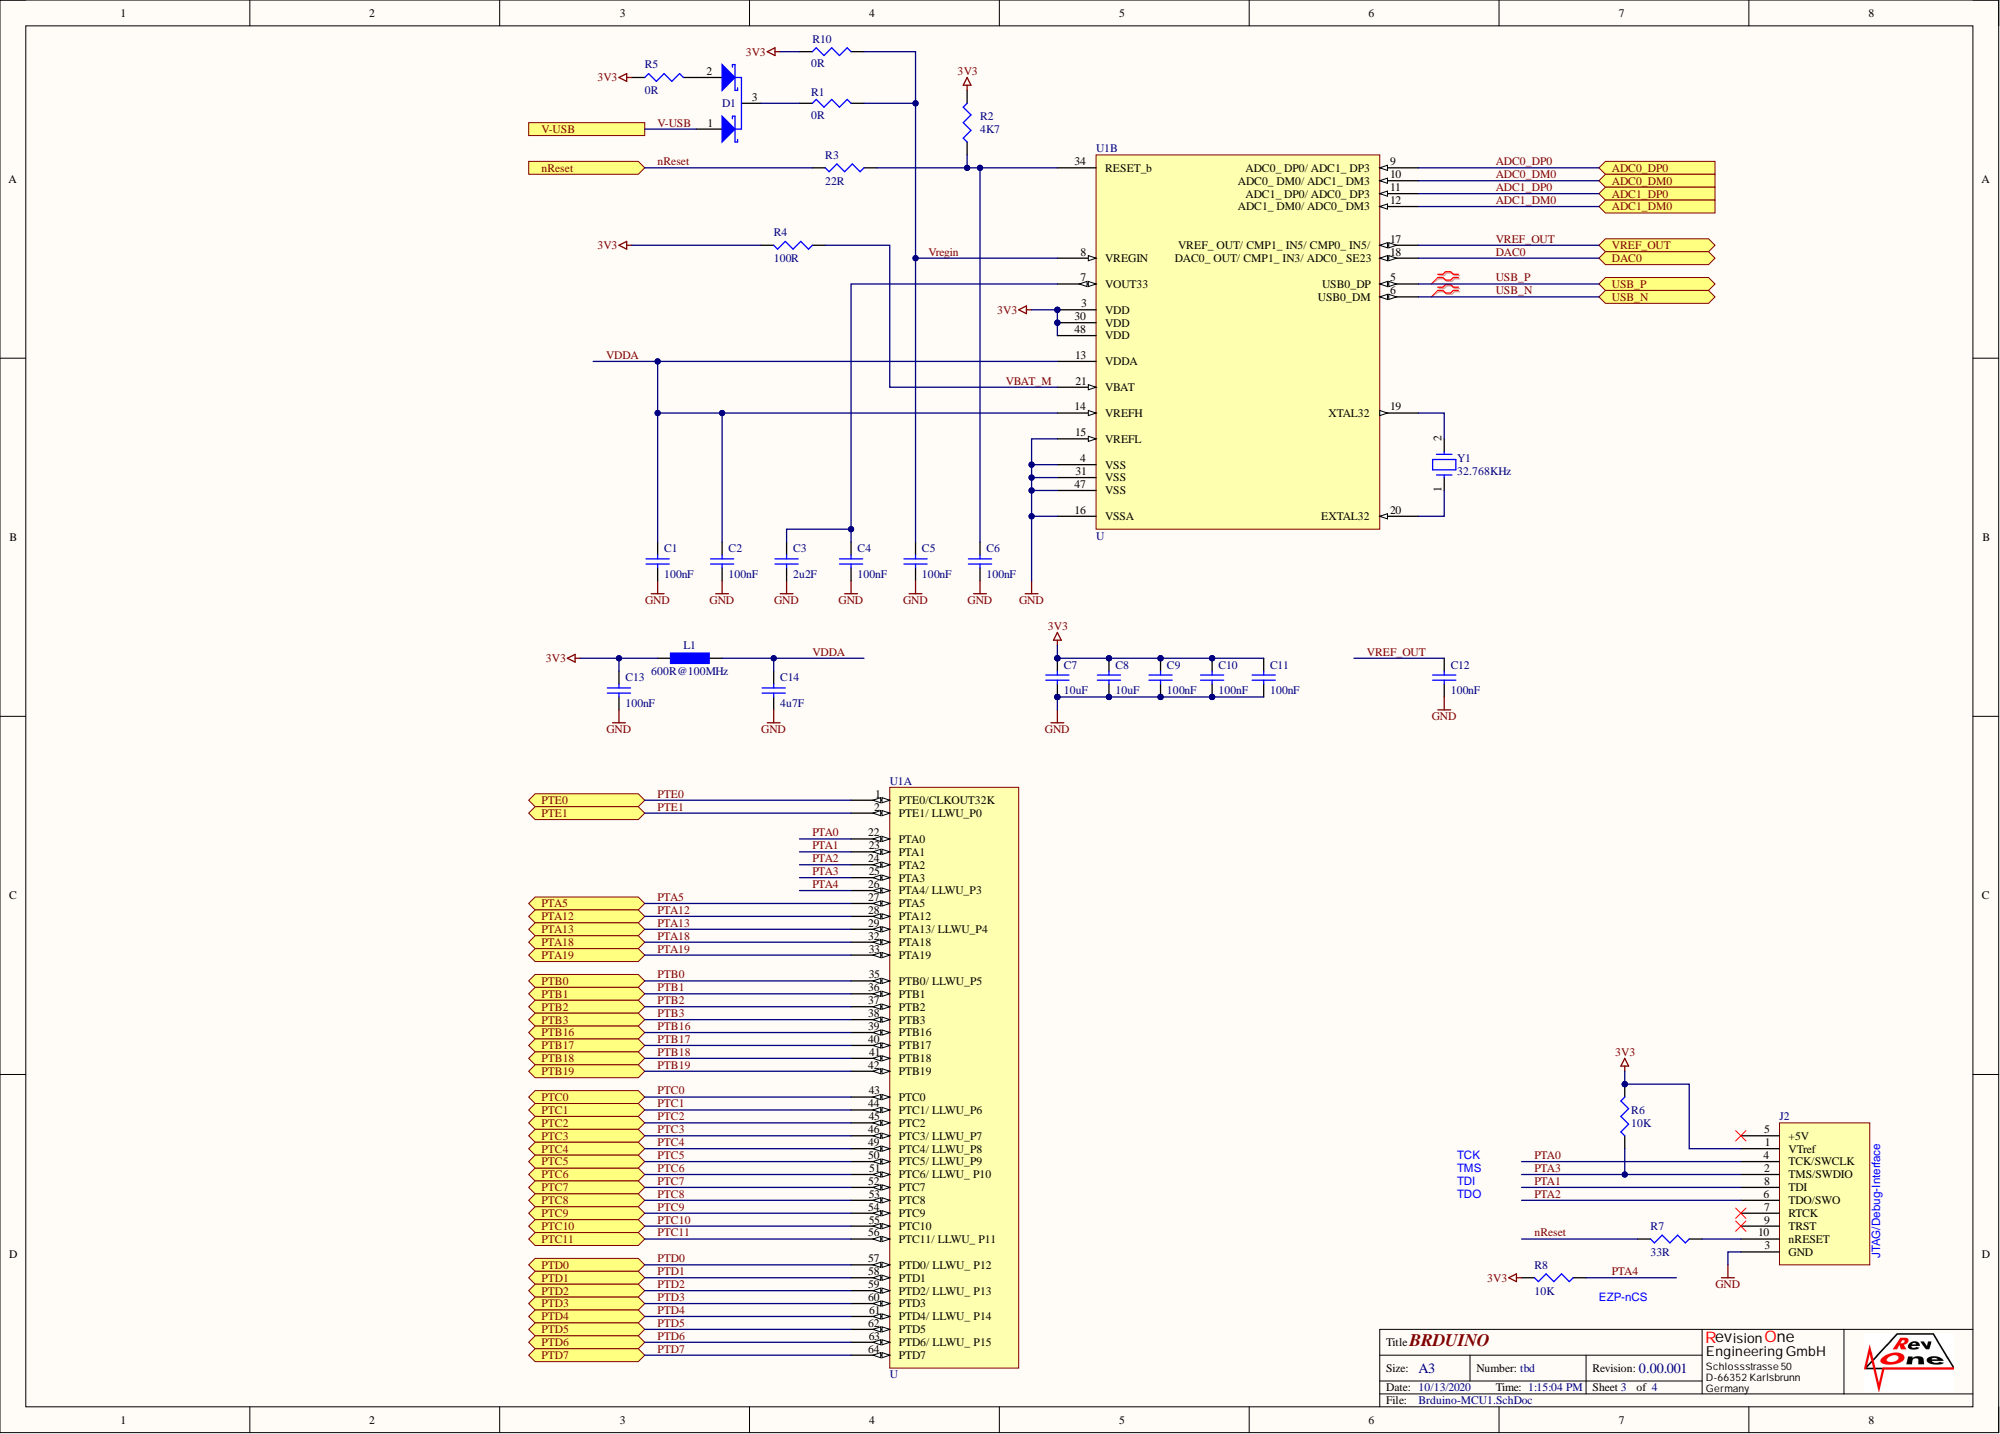
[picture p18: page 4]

VREFH 14

C1 | | VREFL 15

VSS 4
VSS 31
VSS 47

VSSA 16

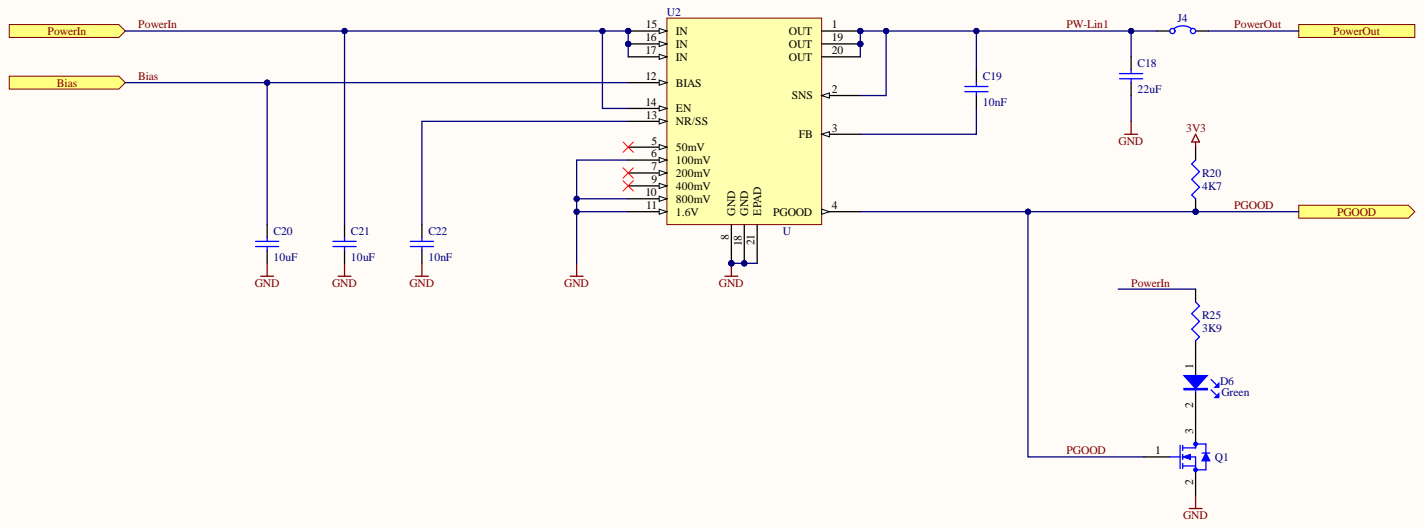
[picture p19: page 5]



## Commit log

2020-08-14 First Release
    [Brduino-MCU-Main.SchDoc, Brduino-MCU1.SchDoc, Brduino-Main.SchDoc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]
2020-08-17 structuring the source tree
    [Brduino-MCU-Main.SchDoc, Brduino-MCU1.SchDoc, Brduino-Main.SchDoc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]
2020-08-17 Libraries addeLibraries addedd Libraries adde# with '#' will be ignored, and an empty message aborts the commit.
    [Brduino.PrjPcb]
2020-09-14 prepared for production
    [Bill of Materials-Brduino-Nano.xlsx, Brduino-MCU-Main.SchDoc, Brduino-MCU1.SchDoc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]
2020-10-13 fixed xtal solder mask and usb connector type
    [Assembly Testpoint Report for Brduino-Nano.csv, Bill of Materials-Brduino-Nano.xlsx, Brduino-MCU-Main.SchDoc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]
2020-10-13 added a 0Ohm resistance
    [Brduino-MCU1.SchDoc, Brduino-Nano.PcbDoc]
2020-10-13 generated data for subcon
    [Bill of Materials-Brduino-Nano.xlsx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]
2020-10-28 added EQ
    [Reply to MS050080-5 (7950016-1) EQ Confirm Sheet.xlsx]
